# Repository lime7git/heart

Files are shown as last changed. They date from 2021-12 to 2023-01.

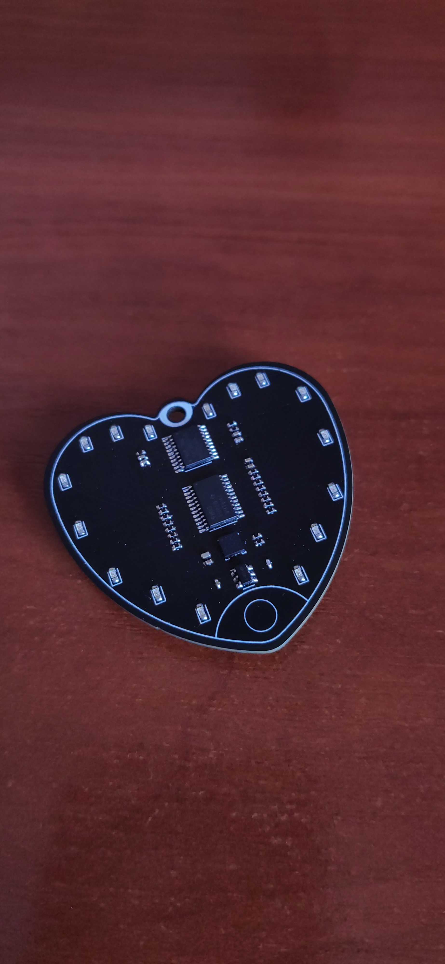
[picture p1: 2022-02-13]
heart-docs/photos/IMG_20220213_142650.jpg

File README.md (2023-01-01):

# heart
A small gift. Heart shape PCB with STM32L0 microcontroller, TCA6416A I2C GPIO expander, LIS3DH accelerometer, BS812A touch sensor and some fancy leds.
 
It can be used as a keychain. It is operates on a CR2450 coin cell battery. There is a few led patterns which can be start by press a touch button or shake. When the device does not recognize any event in 10 seconds it will enter the low power mode and can be woke up only by touching button. In this mode the power consumption is about 25 uA. 




YouTube video short presentation :

[](https://youtu.be/TwGDAYFjpBY "Heart")

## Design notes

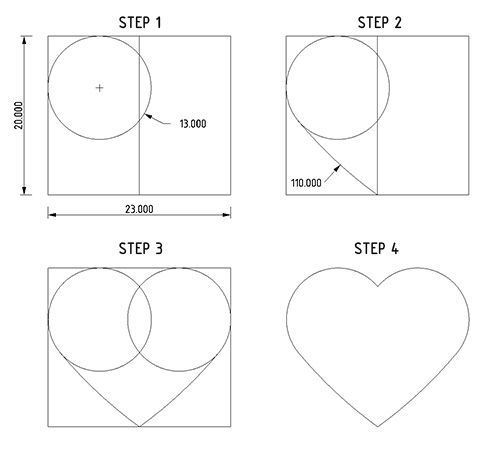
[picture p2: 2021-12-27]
heart-other/heart-shape-example.jpg

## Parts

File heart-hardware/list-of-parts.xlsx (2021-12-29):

Lp. | Name | Description | Qty | Link | Cost [USD]
1 | STM32L031F6P6 | Microcontroller low-power in TSSOP-20 package | 1 | lcsc (https://lcsc.com/product-detail/ST-Microelectronics_STMicroelectronics-STM32L031F6P6_C115208.html) | 2.42
2 | TCA6416APWR | 16-bit GPIO I2C expander | 1 | lcsc (https://lcsc.com/product-detail/I-O-Expanders_Texas-Instruments-TCA6416APWR_C130203.html) | 3.42
3 | MYOUNG MY-2032-22 | CR2032 battery holder | 2 | lcsc (https://lcsc.com/product-detail/Battery-Connectors_MYOUNG-MY-2032-22_C2902339.html) | 0.48
4 | STMicroelectronics LIS3DHTR | 3axis accelerometer | 1 | lcsc (https://lcsc.com/product-detail/Motion-Sensors-Accelerometers_STMicroelectronics-LIS3DHTR_C15134.html) | 1.25
5 | LEDs
6 | Resistors
7 | Capacitors
8 | Power switch
9 | Holtek BS812A-1 | Touch Sensor IC | 1 | lcsc (https://lcsc.com/product-detail/Touch-Sensors_Holtek-Semicon-BS812A-1_C81747.html) | 0.642
10
11
12
13
14
15
16
17
18
19
20
21
22
 |  |  |  |  | 8.212

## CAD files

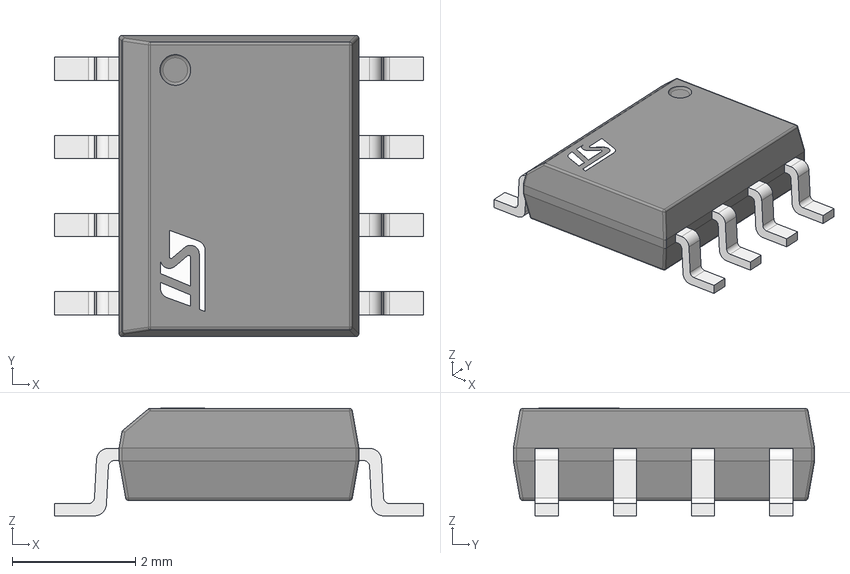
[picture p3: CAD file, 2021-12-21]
heart-hardware/pcb/heart/additional-libs/stm32g0/eec.models/STMicroelectronics_-_STM32G031J6M6.step
6.00 x 4.90 x 1.75 mm
pins
logo1

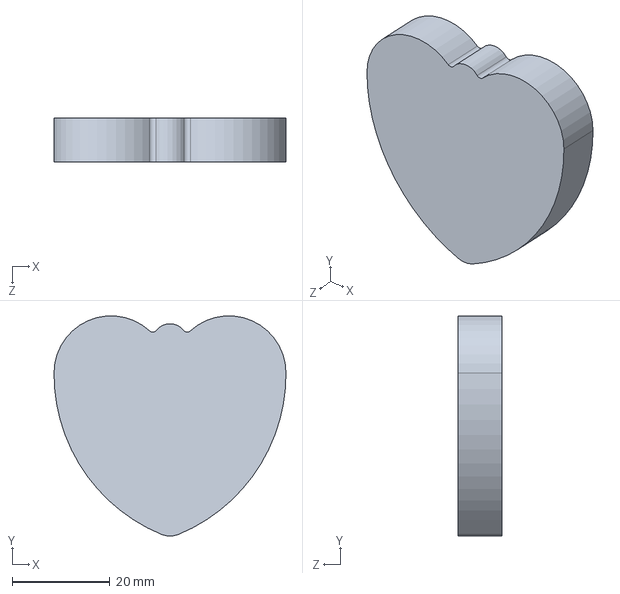
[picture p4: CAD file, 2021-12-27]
heart-other/heart-shape-v1.SLDPRT
47.6 x 45.1 x 9.00 mm

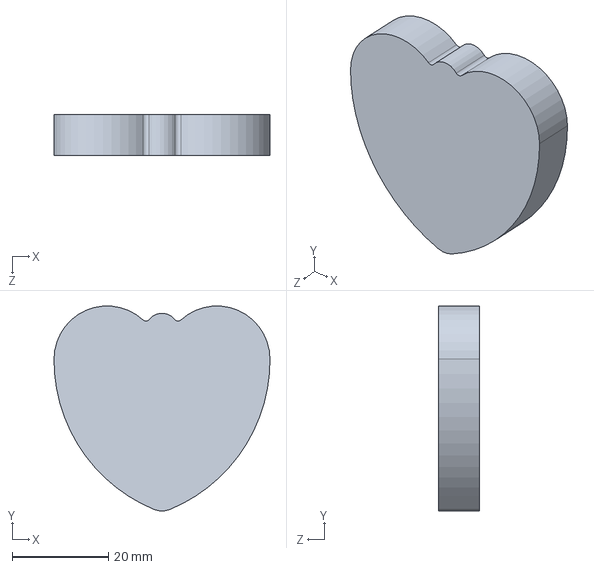
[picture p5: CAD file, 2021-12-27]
heart-other/heart-shape-v1-smaller-for-silk.SLDPRT
44.9 x 42.6 x 8.50 mm

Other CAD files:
heart-hardware/pcb/heart/heart.wrl_1.sldprt
heart-hardware/pcb/heart/heart.wrl_0.sldprt
heart-hardware/pcb/heart/heart.wrl.sldprt
heart-other/heart-shape-v1-smaller-for-silk.DXF
heart-other/heart-shape-v1.DXF

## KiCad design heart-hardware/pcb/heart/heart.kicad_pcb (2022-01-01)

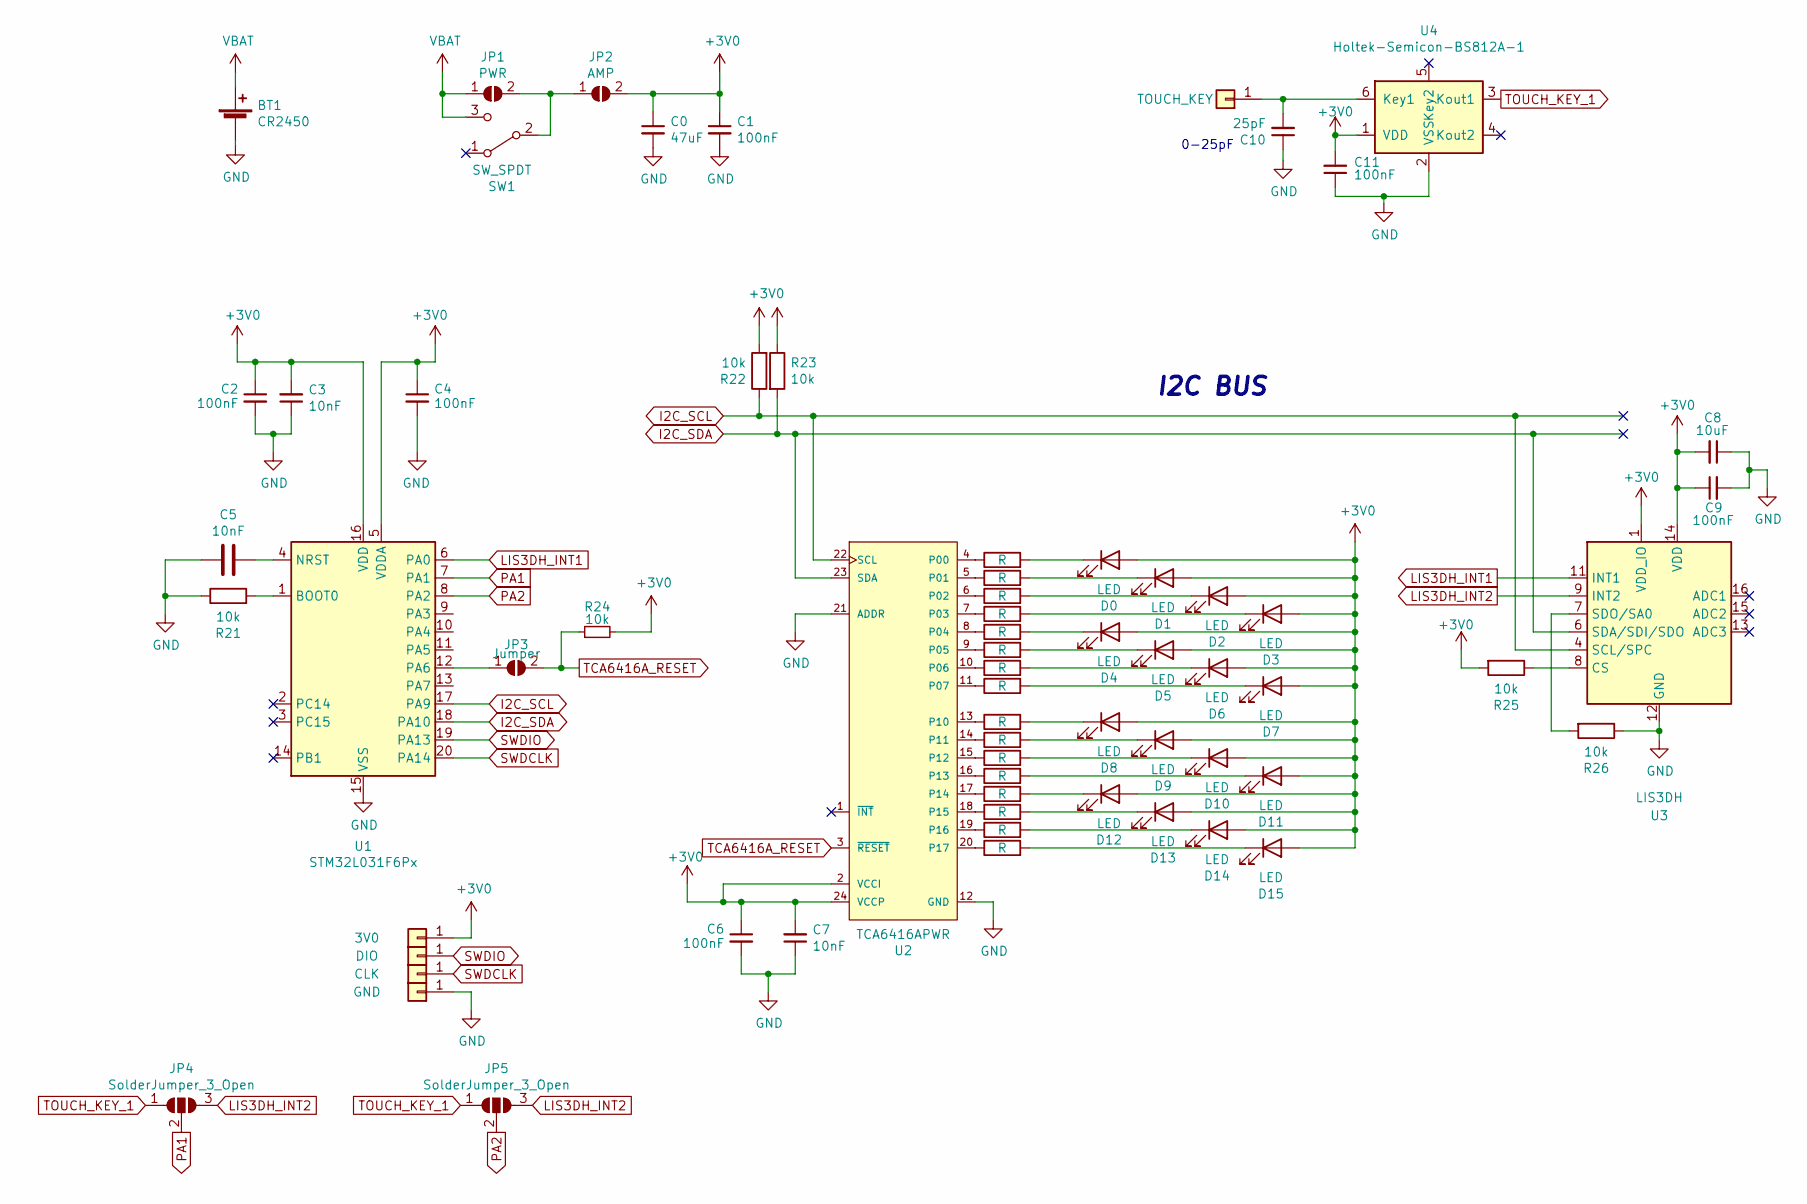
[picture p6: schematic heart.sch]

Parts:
BT1: CR2450; BatteryHolder_Keystone_3008_1x2450; LCSC C238100
C0: 47uF; C_1210_3225Metric_Pad1.33x2.70mm_HandSolder; LCSC C2918508
C1: 100nF; C_0402_1005Metric
C2, C4, C6, C9, C11: 100nF; C_0402_1005Metric; LCSC C60474
C3, C5, C7: 10nF; C_0402_1005Metric; LCSC C60133
C8: 10uF; C_0402_1005Metric; LCSC C15525
C10: 25pF; C_0402_1005Metric; LCSC C295971
D0, D1, D2, D3, D4, D5, D6, D7, D8, D9, D10, D11, D12, D13, D14, D15: LED; LED_0603_1608Metric; LCSC C2846646
J1: 3V0; TestPoint_Pad_1.0x1.0mm
J2: DIO; TestPoint_Pad_1.0x1.0mm
J3: CLK; TestPoint_Pad_1.0x1.0mm
J4: GND; TestPoint_Pad_1.0x1.0mm
J5: TOUCH_KEY; TestPoint_Pad_D4.0mm
JP1: PWR; SolderJumper-2_P1.3mm_Open_RoundedPad1.0x1.5mm
JP2: AMP; SolderJumper-2_P1.3mm_Open_RoundedPad1.0x1.5mm
JP3: Jumper; SolderJumper-2_P1.3mm_Open_RoundedPad1.0x1.5mm
JP4, JP5: SolderJumper_3_Open; SolderJumper-3_P1.3mm_Open_RoundedPad1.0x1.5mm_NumberLabels
R0, R1, R2, R3, R4, R5, R6, R7, R8, R9, R10, R11, R12, R13, R14, R15: R; R_0402_1005Metric; LCSC C258126
R21, R22, R23, R24, R25, R26: 10k; R_0402_1005Metric; LCSC C258091
SW1: SW_SPDT; SW_SPDT_PCM12; LCSC C221841
U1: STM32L031F6Px; TSSOP-20_4.4x6.5mm_P0.65mm; LCSC C115208
U2: TCA6416APWR; TSSOP-24_4.4x7.8mm_P0.65mm; 5V Tolerant IO Yes; LCSC C130203
U3: LIS3DH; LGA-16_3x3mm_P0.5mm_LayoutBorder3x5y; LCSC C15134
U4: Holtek-Semicon-BS812A-1; SOT-23-6; LCSC C81747

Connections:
+3V0: C0.1, C1.1, C2.1, C3.2, C4.1, C6.1, C7.2, C8.2, C9.1, C11.2, D0.2 (A), D1.2 (A), D2.2 (A), D3.2 (A), D4.2 (A), D5.2 (A), D6.2 (A), D7.2 (A), D8.2 (A), D9.2 (A), D10.2 (A), D11.2 (A), D12.2 (A), D13.2 (A), D14.2 (A), D15.2 (A), J1.1, JP2.2 (B), R22.2, R23.1, R24.2, R25.2, U1.5 (VDDA), U1.16 (VDD), U2.2 (VCCI), U2.24 (VCCP), U3.1 (VDD_IO), U3.14 (VDD), U4.1 (VDD)
GND: BT1.2 (-), C0.2, C1.2, C2.2, C3.1, C4.2, C5.2, C6.2, C7.1, C8.1, C9.2, C10.1, C11.1, J4.1, R21.1, R26.1, U1.15 (VSS), U2.12 (GND), U2.21 (ADDR), U3.5 (GND), U3.10 (GND), U3.12 (GND), U4.2 (VSS); also elsewhere on the board
I2C_SCL: R22.1, U1.17 (PA9), U2.22 (SCL), U3.4 (SCL/SPC)
I2C_SDA: R23.2, U1.18 (PA10), U2.23 (SDA), U3.6 (SDA/SDI/SDO)
LIS3DH_INT1: U1.6 (PA0), U3.11 (INT1)
LIS3DH_INT2: JP4.3 (B), JP5.3 (B), U3.9 (INT2); also elsewhere on the board
unnamed: C5.1, U1.4 (NRST)
unnamed: C10.2, J5.1, U4.6 (Key1)
unnamed: D0.1 (K), R0.2
unnamed: D1.1 (K), R1.2
unnamed: D2.1 (K), R2.2
unnamed: D3.1 (K), R3.2
unnamed: D4.1 (K), R4.2
unnamed: D5.1 (K), R5.2
unnamed: D6.1 (K), R6.2
unnamed: D7.1 (K), R7.2
unnamed: D8.1 (K), R8.2
unnamed: D9.1 (K), R9.2
unnamed: D10.1 (K), R10.2
unnamed: D11.1 (K), R11.2
unnamed: D12.1 (K), R12.2
unnamed: D13.1 (K), R13.2
unnamed: D14.1 (K), R14.2
unnamed: D15.1 (K), R15.2
unnamed: JP1.2 (B), JP2.1 (A), SW1.2 (B)
unnamed 25: JP3.1 (A), U1.12 (PA6); also elsewhere on the board
unnamed: R0.1, U2.4 (P00)
unnamed: R1.1, U2.5 (P01)
unnamed: R2.1, U2.6 (P02)
unnamed: R3.1, U2.7 (P03)
unnamed: R4.1, U2.8 (P04)
unnamed: R5.1, U2.9 (P05)
unnamed: R6.1, U2.10 (P06)
unnamed: R7.1, U2.11 (P07)
unnamed: R8.1, U2.13 (P10)
unnamed: R9.1, U2.14 (P11)
unnamed: R10.1, U2.15 (P12)
unnamed: R11.1, U2.16 (P13)
unnamed: R12.1, U2.17 (P14)
unnamed: R13.1, U2.18 (P15)
unnamed: R14.1, U2.19 (P16)
unnamed: R15.1, U2.20 (P17)
unnamed: R21.2, U1.1 (BOOT0)
unnamed: R25.1, U3.8 (CS)
unnamed: R26.2, U3.7 (SDO/SA0)
PA1: JP4.2 (C), U1.7 (PA1); also elsewhere on the board
PA2: JP5.2 (C), U1.8 (PA2); also elsewhere on the board
SWDCLK: J3.1, U1.20 (PA14)
SWDIO: J2.1, U1.19 (PA13)
TCA6416A_RESET: JP3.2 (B), R24.1, U2.3 (~RESET~); also elsewhere on the board
TOUCH_KEY_1: JP4.1 (A), JP5.1 (A), U4.3 (Kout1); also elsewhere on the board
VCC: BT1.1 (+), JP1.1 (A), SW1.3 (C); also elsewhere on the board

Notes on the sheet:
I2C BUS
0-25pF

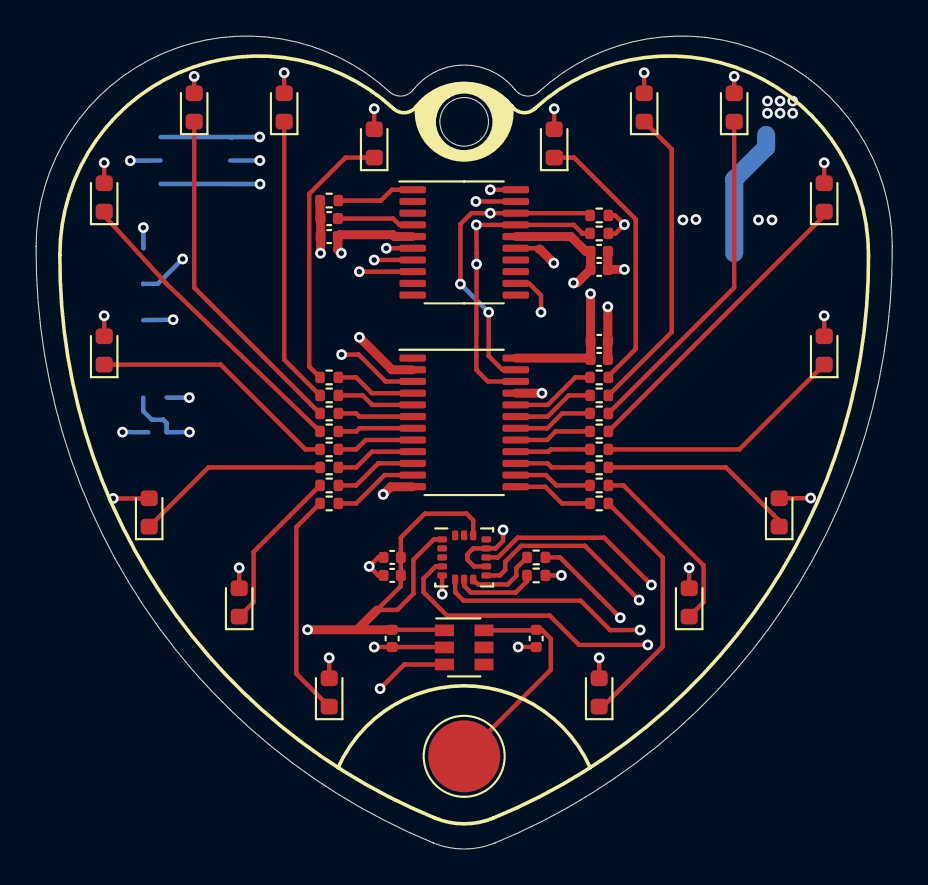
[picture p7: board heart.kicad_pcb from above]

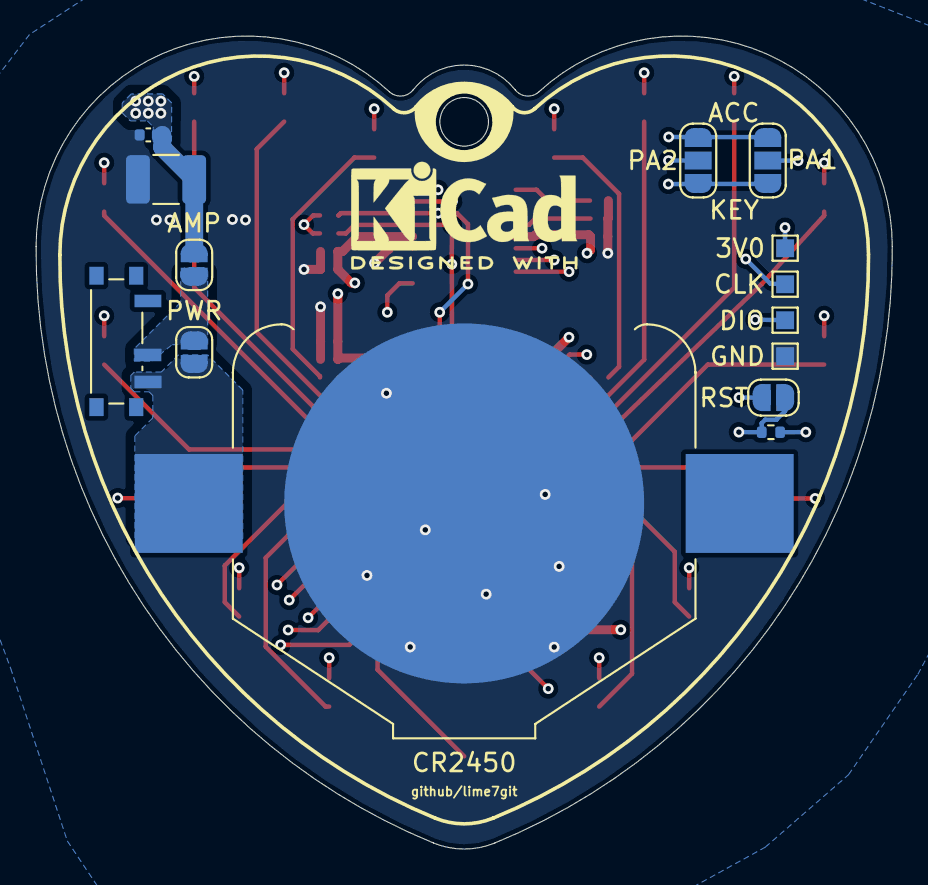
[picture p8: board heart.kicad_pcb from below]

Board: 4 copper layers, 47.6 x 45.2 mm, 66 parts (14 on the bottom side), 52 nets.

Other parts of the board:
CR2450: CR2450; BatteryHolder_Keystone_3008_1x2450
PA1, PA2: SolderJumper_3_Open; SolderJumper-3_P1.3mm_Open_RoundedPad1.0x1.5mm_NumberLabels
RST: Jumper; SolderJumper-2_P1.3mm_Open_RoundedPad1.0x1.5mm

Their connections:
GND: CR2450.2; also elsewhere on the board
LIS3DH_INT2: PA1.3, PA2.3; also elsewhere on the board
unnamed 25: RST.1; also elsewhere on the board
PA1: PA1.2; also elsewhere on the board
PA2: PA2.2; also elsewhere on the board
TCA6416A_RESET: RST.2; also elsewhere on the board
TOUCH_KEY_1: PA1.1, PA2.1; also elsewhere on the board
VCC: CR2450.1; also elsewhere on the board

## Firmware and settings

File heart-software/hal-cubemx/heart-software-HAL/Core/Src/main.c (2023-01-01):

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
/* Includes ------------------------------------------------------------------*/
#include "main.h"
#include "i2c.h"
#include "rtc.h"
#include "gpio.h"

/* USER CODE BEGIN Includes */
#include "state_machine.h"

#include "stdbool.h"

#include <stdio.h>
#include <stdlib.h>
#include <string.h>
/* USER CODE END Includes */


/* USER CODE BEGIN PV */
	bool button_is_pressed = false;
	bool button_was_pressed = false;
	uint32_t button_pressed_time_tmp = 0;
	uint32_t button_pressed_time = 0;
	
	uint32_t previous_tick;
	
	eHEART_STATE state_machine_current_state;

/* USER CODE END PV */

void SystemClock_Config(void);
static void MX_NVIC_Init(void);
/**
  * @brief  The application entry point.
  * @retval int
  */
int main(void)
{
  /* USER CODE BEGIN 1 */
	State_Machine_Set_Next_State(&state_machine_current_state, STATE_INITIALIZATION);

  /* USER CODE END 1 */

  /* MCU Configuration--------------------------------------------------------*/

  /* Reset of all peripherals, Initializes the Flash interface and the Systick. */
  HAL_Init();

  /* Configure the system clock */
  SystemClock_Config();

  /* Initialize all configured peripherals */
  MX_GPIO_Init();
  MX_I2C1_Init();
  MX_RTC_Init();

  /* Initialize interrupts */
  MX_NVIC_Init();
  /* USER CODE BEGIN 2 */
	PWR_PVDTypeDef PVD_Configuration;
 
  __HAL_RCC_PWR_CLK_ENABLE();
  HAL_NVIC_SetPriority(PVD_IRQn, 0, 0);
  HAL_NVIC_EnableIRQ(PVD_IRQn);
	
  PVD_Configuration.PVDLevel = PWR_PVDLEVEL_2;
  PVD_Configuration.Mode = PWR_PVD_MODE_IT_RISING;
 
  HAL_PWR_ConfigPVD(&PVD_Configuration);
	HAL_PWR_EnablePVD();
	
	previous_tick = HAL_GetTick();
  /* USER CODE END 2 */

  /* Infinite loop */
  /* USER CODE BEGIN WHILE */
  while (1)
  {
    /* USER CODE END WHILE */

    /* USER CODE BEGIN 3 */
		
		if( (HAL_GetTick() - previous_tick) >= 10)	// 10 ms loop
		{
			State_Machine_Update(&state_machine_current_state);
			previous_tick = HAL_GetTick();
		}
		
  }
  /* USER CODE END 3 */
}

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
/* USER CODE BEGIN 4 */

void HAL_GPIO_EXTI_Callback(uint16_t GPIO_Pin){ //interrupt handler
    
	if(GPIO_Pin == GPIO_PIN_2)
	{ //check interrupt for specific pin                 
    if(!HAL_GPIO_ReadPin(GPIOA, GPIO_PIN_2) && !button_was_pressed)
		{
			button_is_pressed = true;
      button_pressed_time_tmp = HAL_GetTick();
    }
		if(HAL_GPIO_ReadPin(GPIOA, GPIO_PIN_2) && !button_was_pressed)
		{ 
      button_pressed_time = HAL_GetTick() - button_pressed_time_tmp;
			button_is_pressed = false;
			button_was_pressed = true;
    }
  }
}

/* USER CODE END 4 */
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


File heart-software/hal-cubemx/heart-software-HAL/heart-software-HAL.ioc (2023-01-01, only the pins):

Mcu.UserName=STM32L031F6Px
PA0-CK_IN.GPIO_Label=LIS3DH_INT1
PA0-CK_IN.Signal=GPIO_Input
PA1.GPIO_Label=LIS3DH_INT2
PA1.Signal=GPIO_Input
PA10.Signal=I2C1_SDA
PA13.Signal=SYS_SWDIO
PA14.Signal=SYS_SWCLK
PA2.GPIO_Label=TOUCH_BUTTON
PA2.Signal=GPXTI2
PA6.GPIO_Label=TCA6416A_RESET
PA6.Signal=GPIO_Output
PA9.Signal=I2C1_SCL

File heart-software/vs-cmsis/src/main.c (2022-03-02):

/**
 * @file main.c
 * @author lime7git
 * @date 16.02.2022
 * @brief Main source file
 */

#include "main.h"

int main(void)
{
    Clock_Initialization();
    I2C_Initialization();

		I2C1->CR2 = 0x0;
		I2C1->CR2 = (0x40 << I2C_CR2_SADD_Pos) | (2 << I2C_CR2_NBYTES_Pos) | I2C_CR2_AUTOEND | I2C_CR2_START;

		while((I2C1->ISR & I2C_ISR_TXIS) == RESET){}

		if((I2C1->ISR & I2C_ISR_TXE) == (I2C_ISR_TXE))
		{
		I2C1->TXDR = 0x07;
		}
		
		while((I2C1->ISR & I2C_ISR_TXIS) == RESET){}

		if((I2C1->ISR & I2C_ISR_TXE) == (I2C_ISR_TXE))
		{
		I2C1->TXDR = 0x0;
		}

		Delay_Miliseconds(10);

		I2C1->CR2 = 0x0;
		I2C1->CR2 = (0x40 << I2C_CR2_SADD_Pos) | (2 << I2C_CR2_NBYTES_Pos) | I2C_CR2_AUTOEND | I2C_CR2_START;

		while((I2C1->ISR & I2C_ISR_TXIS) == RESET){}

		if((I2C1->ISR & I2C_ISR_TXE) == (I2C_ISR_TXE))
		{
		I2C1->TXDR = 0x03;
		}

		while((I2C1->ISR & I2C_ISR_TXIS) == RESET){}

		if((I2C1->ISR & I2C_ISR_TXE) == (I2C_ISR_TXE))
		{
		I2C1->TXDR = 0xFF;
		}

    while(true)
    {



    }
}

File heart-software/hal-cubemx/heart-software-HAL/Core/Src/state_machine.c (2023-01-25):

#include "state_machine.h"

extern bool button_was_pressed;
extern uint32_t button_pressed_time;
uint32_t timer = 0;

void State_Machine_Update(eHEART_STATE *state)
{
	switch(*state)
		{
			case STATE_INITIALIZATION:
			{
			
				if((TCA6416A_Initialization() == HAL_OK) && (accelerometer_init() == true))	// initialize gpio expadner and accelerometer
				{
					TCA6416A_Disable_All_LEDs();
					State_Machine_Set_Next_State(state, STATE_IDLE);
				}
				else
				{
					State_Machine_Set_Next_State(state, STATE_FAULT);
				}
				
			
			break;
			}
			
			case STATE_IDLE:
			{
				//static uint32_t timer = 0;
				
				if(timer >= 100)
				{
					timer = 0;
					State_Machine_Set_Next_State(state, STATE_SLEEP);
					return;
				}
				
				if(button_was_pressed || accelerometer_shake_detection())
				{
					timer = 0;
					button_was_pressed = false;
					State_Machine_Set_Next_State(state, STATE_SEQUENCY_RUNNING);
				}
				else
				{
					timer++;
				}
			break;
			}
			case STATE_SEQUENCY_RUNNING:
			{
					static int previous_random = 0;
					static int random_number = 0;
				
					srand(button_pressed_time);
					do{
							random_number = rand() % ((SEQUENCY_LAST - 1) - SEQUENCY_1 + 1) + SEQUENCY_1;
					}while(random_number == previous_random);
					
					previous_random = random_number;
					
					Set_Sequency((SEQUENCIES)random_number);
					Run_Current_Sequency();
					
					State_Machine_Set_Next_State(state, STATE_IDLE);
			break;
			}
			
			case STATE_SLEEP:
			{
				TCA6416A_Disable_All_LEDs();
				accelerometer_enter_low_power();
				
				HAL_RTCEx_DeactivateWakeUpTimer(&hrtc);
				HAL_SuspendTick();
				HAL_PWR_EnterSTOPMode(PWR_LOWPOWERREGULATOR_ON,PWR_STOPENTRY_WFI); // 25uA
				
				HAL_ResumeTick();
				
				if(*state != STATE_SLEEP) break;
				
				if((TCA6416A_Initialization() == HAL_OK) && (accelerometer_init() == true))	// initialize gpio expadner and accelerometer
				{
					TCA6416A_Disable_All_LEDs();
					State_Machine_Set_Next_State(state, STATE_IDLE);
				}
				else
				{
					State_Machine_Set_Next_State(state, STATE_FAULT);
				}
			
			break;
			}
			
			case STATE_LOW_BATTERY:
			{
				static bool doOnce = true;
				
				if(doOnce) 
				{
					TCA6416A_Disable_All_LEDs();
					accelerometer_enter_low_power();
					doOnce = false;
				}
				
				HAL_PWR_EnablePVD();
				
				
				if(__HAL_PWR_GET_FLAG(PWR_FLAG_PVDO) == RESET)
				{
					State_Machine_Set_Next_State(state, STATE_INITIALIZATION);	
					doOnce = true;
					return;
				}
				
				TCA6416A_Write(TCA6416A_OUTPUT_PORT_0_ADDRESS, 127);
				HAL_Delay(500);
				TCA6416A_Disable_All_LEDs();
				HAL_Delay(500);
				TCA6416A_Write(TCA6416A_OUTPUT_PORT_0_ADDRESS, 127);
				HAL_Delay(500);
				TCA6416A_Disable_All_LEDs();
				
				
				HAL_RTCEx_SetWakeUpTimer_IT(&hrtc, 0x61A8, RTC_WAKEUPCLOCK_RTCCLK_DIV16);
				HAL_SuspendTick();
				
				//HAL_PWR_EnterSLEEPMode(PWR_LOWPOWERREGULATOR_ON,PWR_STOPENTRY_WFI); // w sleep modzie na takiej konfiguracji bylo zuzycie na poziomie 50uA
				HAL_PWR_EnterSTOPMode(PWR_LOWPOWERREGULATOR_ON,PWR_STOPENTRY_WFI); // 25uA
				
				HAL_ResumeTick();
				HAL_RTCEx_DeactivateWakeUpTimer(&hrtc);
				
			break;
			}
			
			default: 
				State_Machine_Set_Next_State(state, STATE_IDLE);		
			break;
		}
}

void State_Machine_Set_Next_State(eHEART_STATE *current_state, eHEART_STATE new_state)
{
	*current_state = new_state;
}

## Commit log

2021-12-21 PCB Design
    Left probably only add some decoupling capacitors.
    [STMicroelectronics_-_STM32G031J6M6.step, heart.kicad_pcb, heart.sch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]
2021-12-21 Added current probe test points
    [heart.sch]
2021-12-22 Added decoupling capacitors
    [heart.sch]
2021-12-23 Schematic complete (ver. 1.0), starting work on a pcb and choose footprints
    [heart.kicad_pcb, heart.sch]
2021-12-23 Added vector graphics of heart shape, used as a pcb edges
    [Love_Heart_SVG.dxf]
2021-12-24 PCB design update
    [heart.kicad_pcb, heart.sch]
2021-12-24 Bottom layer component set
    [heart.kicad_pcb]
2021-12-26 Added touch key
    [heart.kicad_pcb, heart.sch]
2021-12-27 Changed battery from 2x CR2032 to 1x CR2450
    [heart.kicad_pcb, heart.sch]
2021-12-27 New final heart shape
    [Love_Heart_SVG.dxf, heart-shape-v1-smaller-for-silk.DXF, heart-shape-v1-smaller-for-silk.SLDPRT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]
2021-12-27 New heart shape, battery change, top layer component placed v1
    [heart.kicad_pcb, heart.sch]
2021-12-27 All components initially placed
    [heart.kicad_pcb]
2021-12-27 Component pacement v1
    [heart.kicad_pcb]
2021-12-27 Start routing traces
    [heart.kicad_pcb]
2021-12-27 Added jumper to choose interuppt lines
    [heart.kicad_pcb, heart.sch]
2021-12-27 Routing in progress
    [heart.kicad_pcb]
2021-12-28 Some trace routed, backup with vias on leds to trace route in inner layer
    [heart.kicad_pcb]
2021-12-28 Gerber files for test
    [heart-B_Cu.gbr, heart-B_Mask.gbr, heart-B_Paste.gbr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]
2021-12-28 Route completed
    [heart.kicad_pcb]
2021-12-28 Added documentation for touch sensor ic
2021-12-28 Added addnotation to github's profile
    [heart.kicad_pcb]
2021-12-28 Version 1.0
    [heart.kicad_pcb]
2021-12-28 Production files gerber ver. 1.01
    [heart-B_Cu.gbr, heart-B_Mask.gbr, heart-B_Paste.gbr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]
2021-12-28 Version 1.01, change power planes clearance
    [heart.kicad_pcb, heart.sch]
2021-12-29 Gerber files ver 1.02
    [heart-B_Cu.gbr, heart-B_Mask.gbr, heart-B_Paste.gbr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]
2021-12-29 Version 1.02
    [heart.kicad_pcb, heart.sch, list-of-parts.xlsx]
2022-01-01 Generate drill map for produce
    [heart.kicad_pcb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]
2022-01-30 Create ibom.html, an interactive HTML bom project from 'openscopeproject'
    Using https://github.com/openscopeproject/InteractiveHtmlBom
2022-01-31 Test software update
    3 sequences starting with a touch button
2022-02-08 Trying to get 3d model file from kicad to make a solidwork's render
    [heart.wrl.sldprt, heart.wrl_0.sldprt, heart.wrl_1.sldprt]
2022-02-16 Visual studio stm32cube framework test software
2022-02-16 Visual studio cmsis framework software main
2022-02-16 clock and i2c configuration
2022-02-16 I2C not tested yet
2022-02-16 Working on i2c bus
2022-03-02 cmsis i2c communication problems
    [i2c.c, main.c, main.h]
2022-03-13 touch button input capture random sequencies
2022-06-22 accelerometer lis3dh data polling
2022-06-22 accelerometer; shake detection, double click detection
2022-10-06 first iteration of pvd low battery voltage detection
2022-10-06 low battery detection
2022-10-09 rtc wakeup, better low power modes
2022-10-09 dwa tryby uruchamiania, touch button mode i acc mode
2023-01-01 100Hz accelerometer data output
2023-01-06 sprawdzanie stanu flagi pvdo w kazdej petli low battery state

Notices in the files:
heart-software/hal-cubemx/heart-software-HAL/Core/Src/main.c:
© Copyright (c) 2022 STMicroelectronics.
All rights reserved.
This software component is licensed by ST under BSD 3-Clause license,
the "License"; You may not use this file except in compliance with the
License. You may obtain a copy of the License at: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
